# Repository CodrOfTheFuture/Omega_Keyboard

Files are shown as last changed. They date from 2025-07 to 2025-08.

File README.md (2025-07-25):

# Omega

### Description:

Omega is an open source corne wireless keyboard that is built with the nice!nano v2. It includes an oled screen for each side and a low profile look. It looks great and great for coders, writers and any person who uses there keyboards a lot. In addition, Omega is built with the firmware called ZMK to allow bluetooth pairing.

### Why did I even make this:

A big reason why I started making this is because a problem I had with modern keyboards. They are not ergonomic and can be very damaging to someones wrists if they are typing for a long time. And since I am a coder who uses their keyboard a lot (i use vim), I face this problem.

Full 3d model of Omega
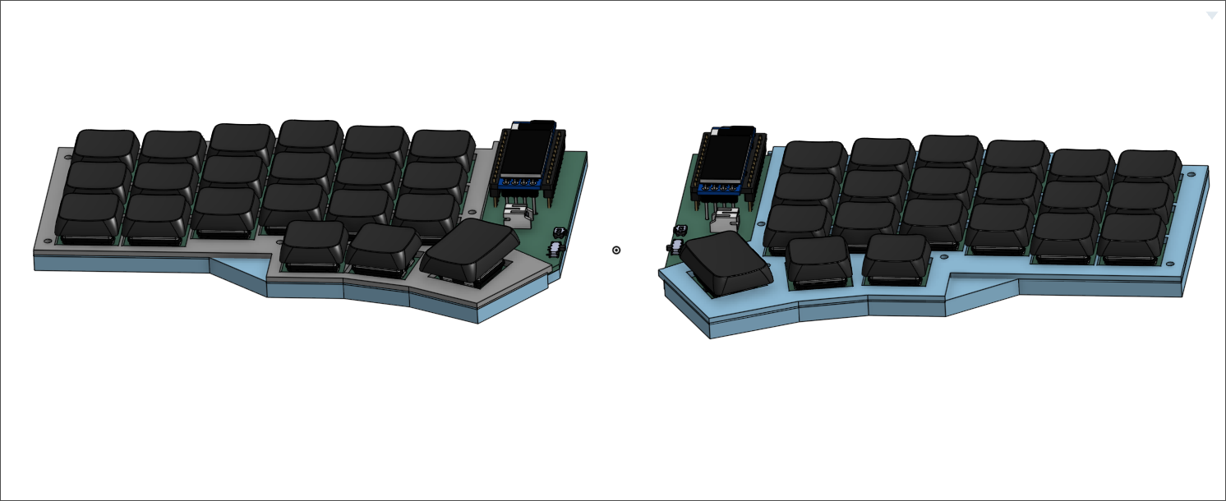
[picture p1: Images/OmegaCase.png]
full model


PCB:
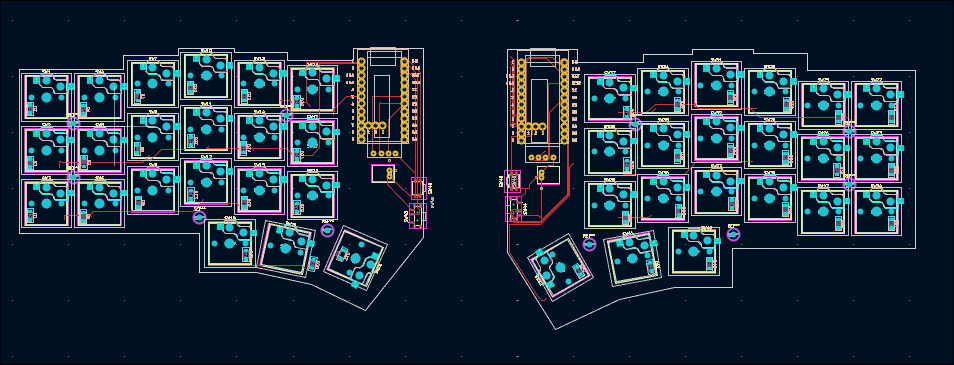
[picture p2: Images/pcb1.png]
Omega pcb


Schematics:
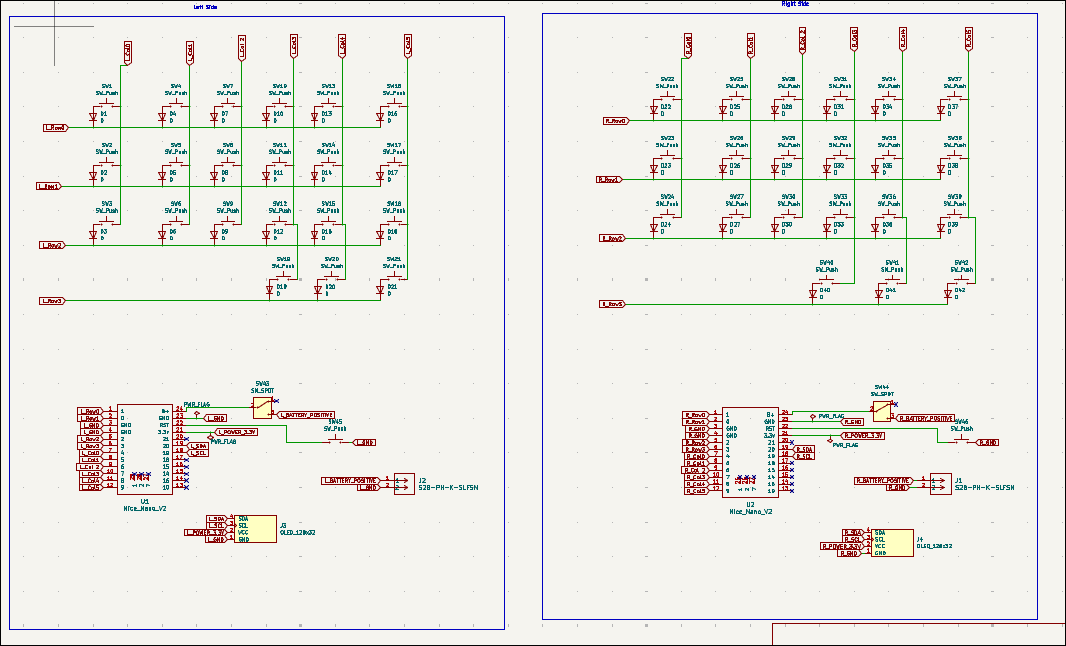
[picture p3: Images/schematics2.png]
Omega schematics


|Name |Qty |Final Price- USD |Link |
|---|----|---|---|
|ProMicro | 2  | 5.72 | https://www.aliexpress.us/item/1005001621678794.html |
|Lithium Battery 110mAh| 2  | 5.77 | https://www.aliexpress.com/item/1005005348368664.html  |
|Machine Sockets | 1  | 2.83 | https://www.aliexpress.com/item/4001122376295.html |
|Machine Pins | 1  | 3.99 | https://www.aliexpress.com/item/32858430771.html |
|PCB | 2  | ~15.00 (including $20 discount & shipping) | https://jlcpcb.com/ |
|3d printed case | 2  | 10.00 | printing locally |
|OLED | 2  | 6.94 | https://www.aliexpress.us/item/1005005301005280.html |
|Choc Switches | 50 | 25.00 | https://www.aliexpress.com/item/1005008883418065.html  |
|choc keycaps | 42 | 5.00 | gonna print them locally |
|SMD diodes | 100| 2.08 | https://www.aliexpress.com/item/1005004629414782.html  |
|Kalih Hotswaps | 50 | 6.85 | https://www.aliexpress.com/item/1005008543325730.html  |
|Power Switch | 5  | 0.69 | https://lcsc.com/product-detail/image/SSSS811101_C109335.html |
|Reset Button | 5  | 0.17 | https://lcsc.com/product-detail/Tactile-Switches_G-Switch-GT-TC041B-H036-L1N_C2686893.html |
|Battery Jack | 5  | 0.71 | https://lcsc.com/product-detail/image/S2B-PH-K-S-LF-SN_C173752.html |
|Screw Kit | 1  | 3.26 | https://www.aliexpress.com/item/1005008459241647.html  |
|Soldering Iron | 1  | 13.98 | https://www.amazon.com/Soldering-Adjustable-Temperature-Electronics-Desoldering/dp/B097XX76V4/  |
|Shipement & other fees| | 37.18 | n/a |
|Total | | 145.97 | |

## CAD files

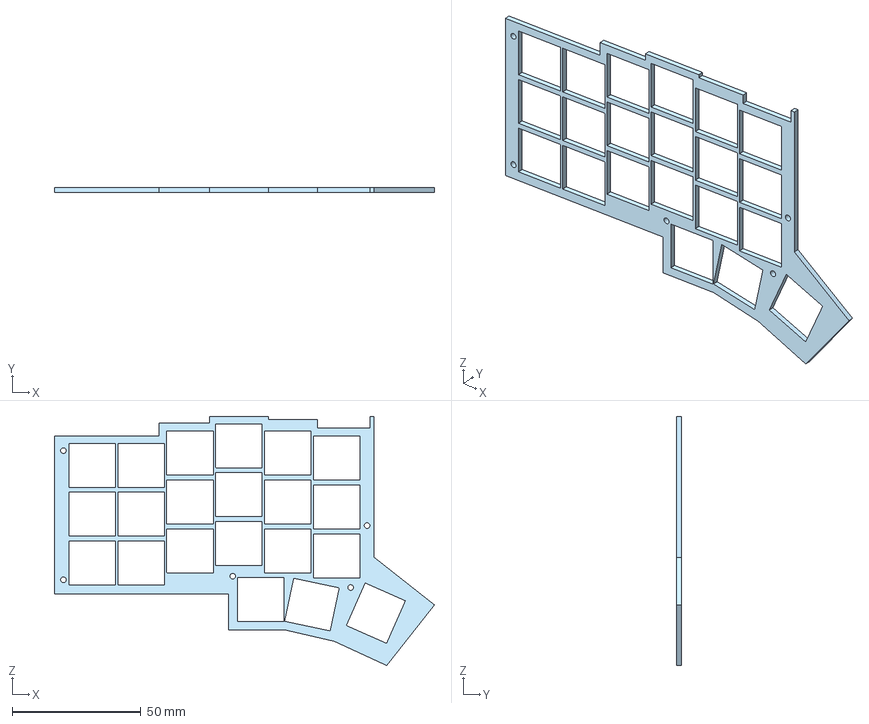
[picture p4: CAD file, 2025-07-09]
Production/3d print/left side/topLeft.step
147.7 x 2.00 x 96.8 mm

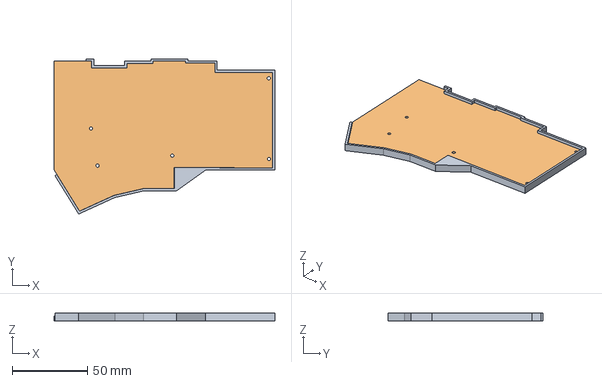
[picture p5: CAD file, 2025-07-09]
Production/3d print/right side/bottomRight.step
147.0 x 103.2 x 5.00 mm

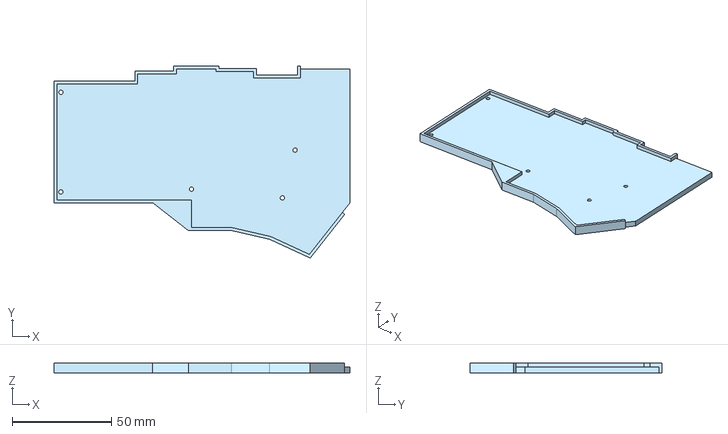
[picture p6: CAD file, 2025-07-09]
Production/3d print/left side/bottomLeft.step
149.2 x 96.8 x 5.00 mm

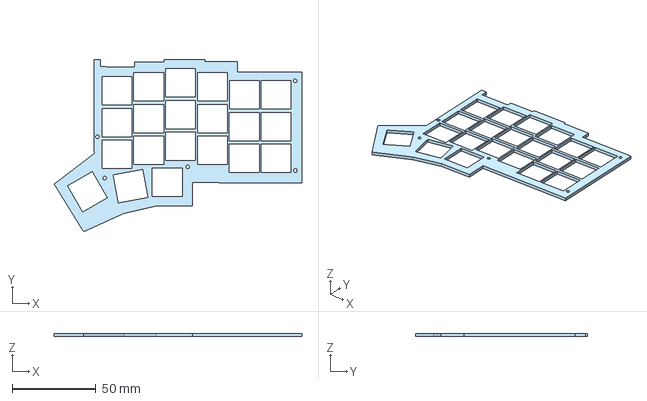
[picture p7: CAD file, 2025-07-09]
Production/3d print/right side/topRight.step
148.3 x 103.1 x 2.00 mm

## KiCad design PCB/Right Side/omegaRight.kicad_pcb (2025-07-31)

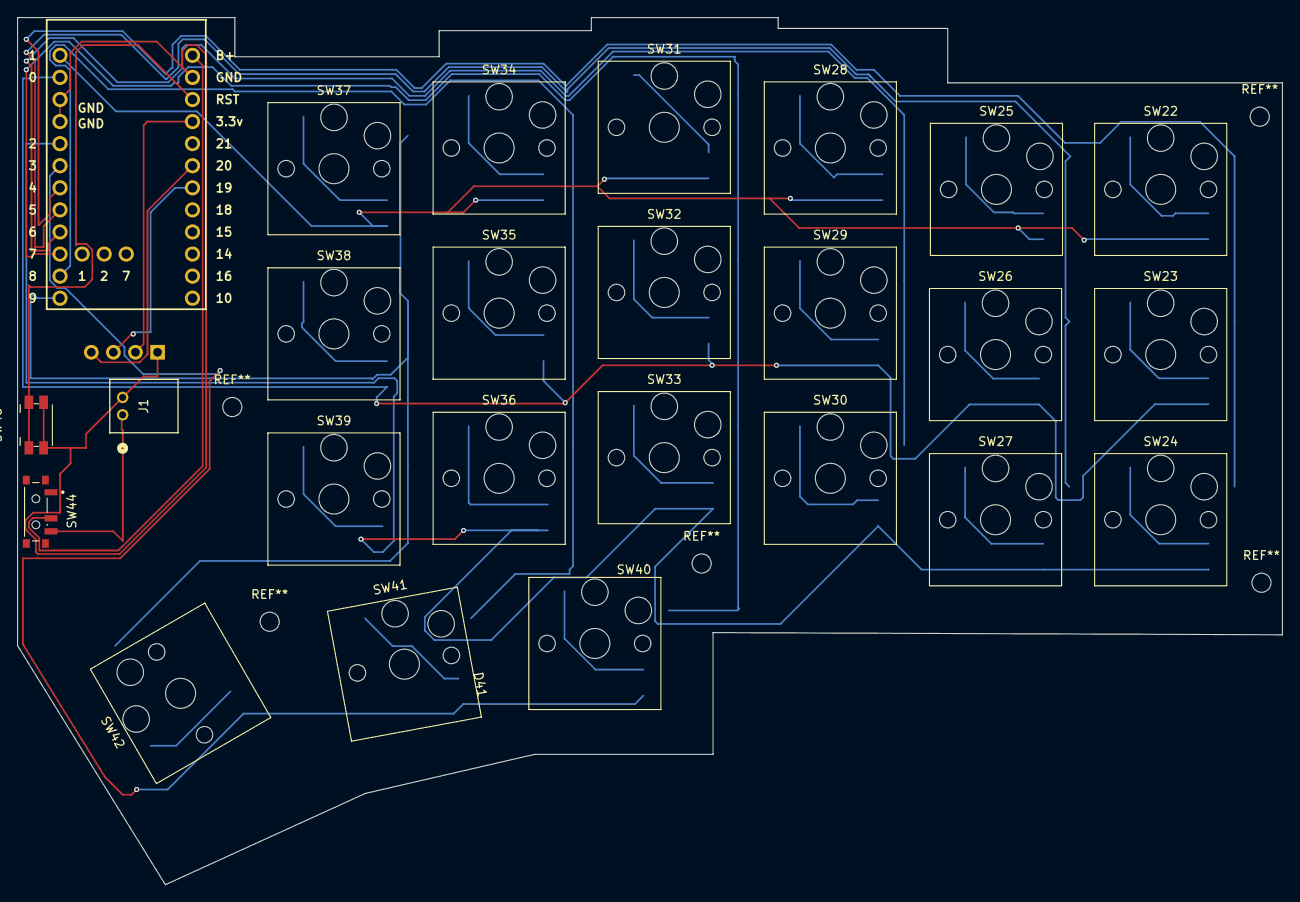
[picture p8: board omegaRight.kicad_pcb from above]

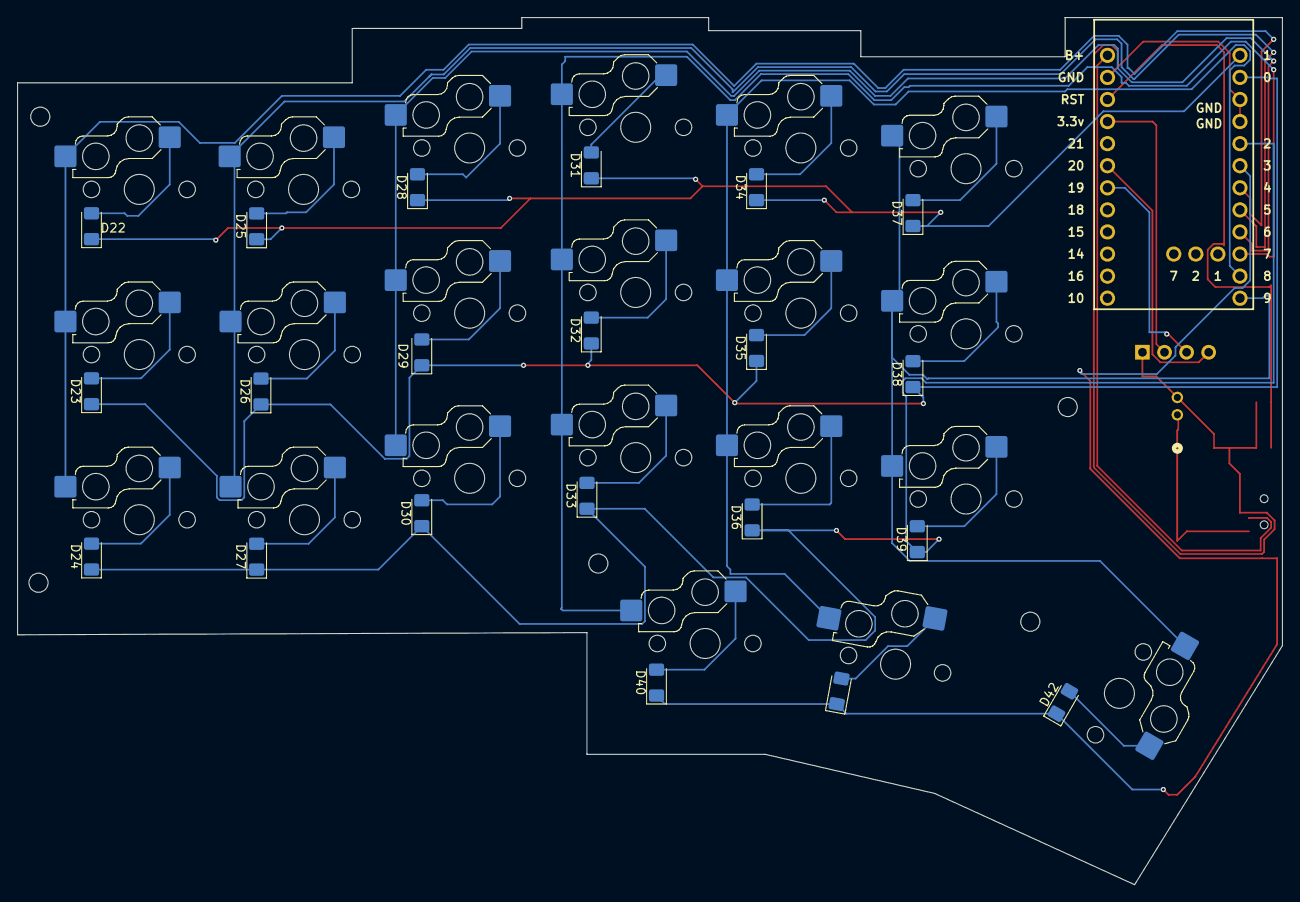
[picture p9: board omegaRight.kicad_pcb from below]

Board: 2 copper layers, 145.5 x 99.8 mm, 47 parts (21 on the bottom side), 38 nets.

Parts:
D22, D23, D24, D25, D26, D27, D28, D29, D30, D31, D32, D33, D34, D35, D36, D37, D38, D39, D40, D41, D42: D; D_1206_3216Metric_Pad1.42x1.75mm_HandSolder
J1: S2B-PH-K-SLFSN; CONN_S2B-PH-K-S_JST
J4: OLED_128x32
SW22, SW23, SW24, SW25, SW26, SW27, SW28, SW29, SW30, SW31, SW32, SW33, SW34, SW35, SW36, SW37, SW38, SW39, SW40, SW41, SW42: SW_Push; Hotswap_Choc_V1_1.00u
SW44: SW_SPDT; SW_SSSS811101
SW46: SW_Push; Panasonic_EVQPUJ_EVQPUA
U2: Nice_Nano_V2

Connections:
unnamed: D22.2 (A), SW22.1
unnamed: D23.2 (A), SW23.1
unnamed: D24.2 (A), SW24.1
unnamed: D25.2 (A), SW25.1
unnamed: D26.2 (A), SW26.1
unnamed: D27.2 (A), SW27.1
unnamed: D28.2 (A), SW28.1
unnamed: D29.2 (A), SW29.1
unnamed: D30.2 (A), SW30.1
unnamed: D31.2 (A), SW31.1
unnamed: D32.2 (A), SW32.1
unnamed: D33.2 (A), SW33.1
unnamed: D34.2 (A), SW34.1
unnamed: D35.2 (A), SW35.1
unnamed: D36.2 (A), SW36.1
unnamed: D37.2 (A), SW37.1
unnamed: D38.2 (A), SW38.1
unnamed: D39.2 (A), SW39.1
unnamed: D40.2 (A), SW40.1
unnamed: D41.2 (A), SW41.1
unnamed: D42.2 (A), SW42.1
unnamed: SW44.2 (B), U2.24 (B+)
unnamed: SW46.1, U2.22 (RST)
R_BATTERY_POSITIVE: J1.1, SW44.3 (C)
R_Col0: SW22.2, SW23.2, SW24.2, U2.7 (4)
R_Col1: SW25.2, SW26.2, SW27.2, U2.8 (5)
R_Col3: SW31.2, SW32.2, SW33.2, SW40.2, U2.10 (7)
R_Col4: SW34.2, SW35.2, SW36.2, SW41.2, U2.11 (8)
R_Col5: SW37.2, SW38.2, SW39.2, SW42.2, U2.12 (9)
R_Col 2: SW28.2, SW29.2, SW30.2, U2.9 (6)
R_GND: J1.2, J4.1 (GND), SW46.2, U2.3 (GND), U2.4 (GND), U2.23 (GND)
R_POWER_3.3V: J4.2 (VCC), U2.21 (3.3v)
R_Row0: D22.1 (K), D25.1 (K), D28.1 (K), D31.1 (K), D34.1 (K), D37.1 (K), U2.1
R_Row1: D23.1 (K), D26.1 (K), D29.1 (K), D32.1 (K), D35.1 (K), D38.1 (K), U2.2 (0)
R_Row2: D24.1 (K), D27.1 (K), D30.1 (K), D33.1 (K), D36.1 (K), D39.1 (K), U2.5 (2)
R_Row3: D40.1 (K), D41.1 (K), D42.1 (K), U2.6 (3)
R_SCL: J4.3 (SCL), U2.18 (19)
R_SDA: J4.4 (SDA), U2.19 (20)

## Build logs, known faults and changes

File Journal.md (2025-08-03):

# OMEGA

### total hours spent: 21 hrs

## Day 1 - May 22nd

time spent: 0.5

Today is the first day of starting the split keyboard project, named the "Omega Grid". For this keyboard, my whole goal is to add features that I find missing in my current keyboard. I've made a list of things the Omega needs to have for it to be the "perfect" keyboard for me.

Features:
* A slim keyboard, with low profile switches
* A Wireless split keyboard
* Orttholinear layout
* Unique designs
* Hot swabable

## Day 2 - May 30th

time spent: 0.5 hrs

Now that I know what features I want in my keyboard, I need to know what parts of the keyboard I need to make these features real.

**MCU**: I see lots of recommendations for the **nice!nano v2**. And there's reasons for it. Its super slimm, which fits for my Slim keyboard and it has the nRF52840 chip which is good for bluetooth. In addition, it supports **ZMK** which I will use for my firmware.

**Screen**: For my screen on my keyboard, I will use the **nice!view**. Yes this is a bit expensive but honestly worth it. Its 30hz, draws low power (big win for wireless keyboards), and decent display.

**Switches**: Choosing my switches wasn't hard, I chose the **Red Kailh Low Profile Choc** Switches. They have good ergonomics, sound good, and comfortable to type on.

**Case**: My case will be 3d print, making it easy to make custom designs and cheap.

## Day 3 - July 4th

time spend: 5hrs

I just spent a lot of time on creating a budget and doing more research on the parts I chose in day 2. So I have only change.
I need to remove the screen from my project. This is because the nice!view is way too expensive and I rather just save up for a
nice!view later on when I have the keyboard intead of using a cheap oled.

### Budget
| Item | Price (USD) |
|---|---|
| Nice!Nano | $51.10 |
| Lithium Battery | $8.76 |
| Solder Sockets | $14.60 |
| PCB (idk price) | $21.90 |
| 3D printed case | $5.11 |
| Switches | $12.64 |
| KeyCaps | $21.90 |
| Diodes | $1.01 |
| Kalih Hotswaps | $1.01 |
| Power Switch | $2.19 |
| Reset Button | $2.19 |
| Battery Jack | $1.46 |
| Screws Kits | $3.23 |

In addition, I also did my schematics:

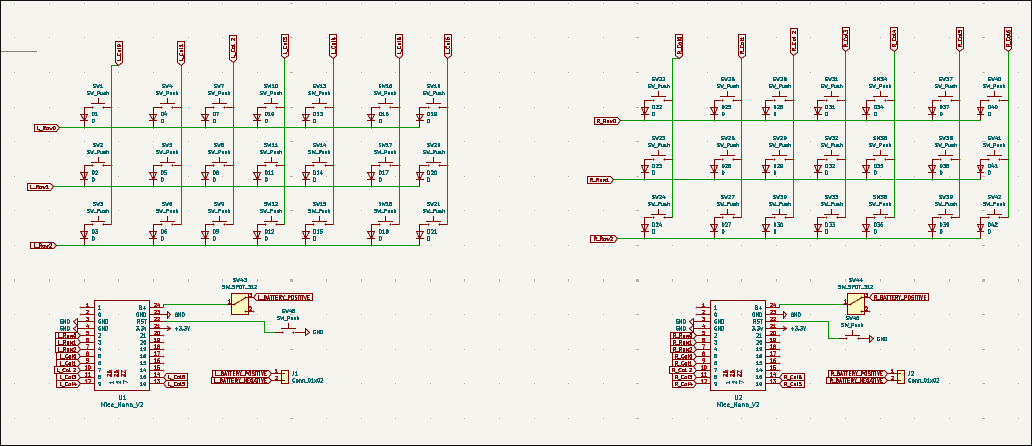
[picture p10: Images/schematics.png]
Schematics V1


## Day 4,5,6 - June 5th - 7th

time spent: 10hrs

After reflecting more about my componenet choices on day 3, I choose to use a normal 128x32 oled screen from aliexpress instead of a nice!view since I still really want a display but dont want to pay that much. In addition, I have tweaked a bit of things in the budget like alternating some of my items to aliexpress (solder sockets, etc). For these 3 days, I have been focusing on building my pcb and schematics and having a efficient pcb which suits my needs. I've also done lots of research of how I was going to make the layout of my pcb. A great source that helped me was the this [repo](https://github.com/foostan/crkbd/?tab=readme-ov-file) with a great diagram here:

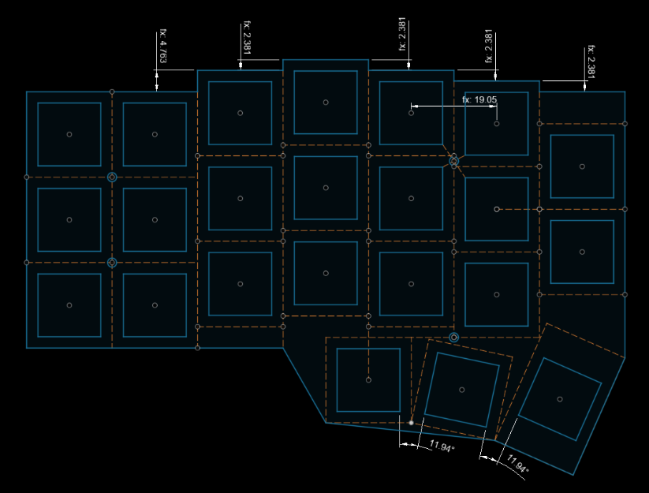
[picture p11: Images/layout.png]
Corne Layout Diagram


My current building status for my pcb and schematics are not 100% finished but they are mostly finished I would say. Here is the progress:

Schematics:
Schematics2

PCB:
Pcb1

## Day 7 - June 8th

time spent: 5hrs

FINALLY! Today is the day I finished the Omega Project! In Day 7th, I doubled checked my schematics and pcb and made a case in onshape to 3d print. I also did the firmware (ZMK) which didnt take much time at all. The case isnt really complex at all, its just a bottom case and top case with the mounting holes, I also made sure it was low profile for my build.

Here is the case design:

Case

THANK YOU FOR READING

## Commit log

2025-07-09 commiting Omega
    [BOM.csv, bottomLeft.step, bottomRight.step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]
2025-07-09 fixing budget
    [BOM.csv]
2025-07-25 changed BOM and readme
    [BOM.csv]
2025-07-25 updated BOM and README again
    [BOM.csv]
